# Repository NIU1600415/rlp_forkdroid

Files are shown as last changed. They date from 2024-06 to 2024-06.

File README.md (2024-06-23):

# FORKDROID

Automated forklift with machine vision.

## What is this?

This repository tracks the development of Forkdroid, a machine-vision powered robot which automates moving materials over short distances.
The Forkdroid prototype is a small-form robot actuated by SG90 servomotors with a Raspberry Pi Zero & Pi Camera.

Forkdroid in action

#### Assembled prototype

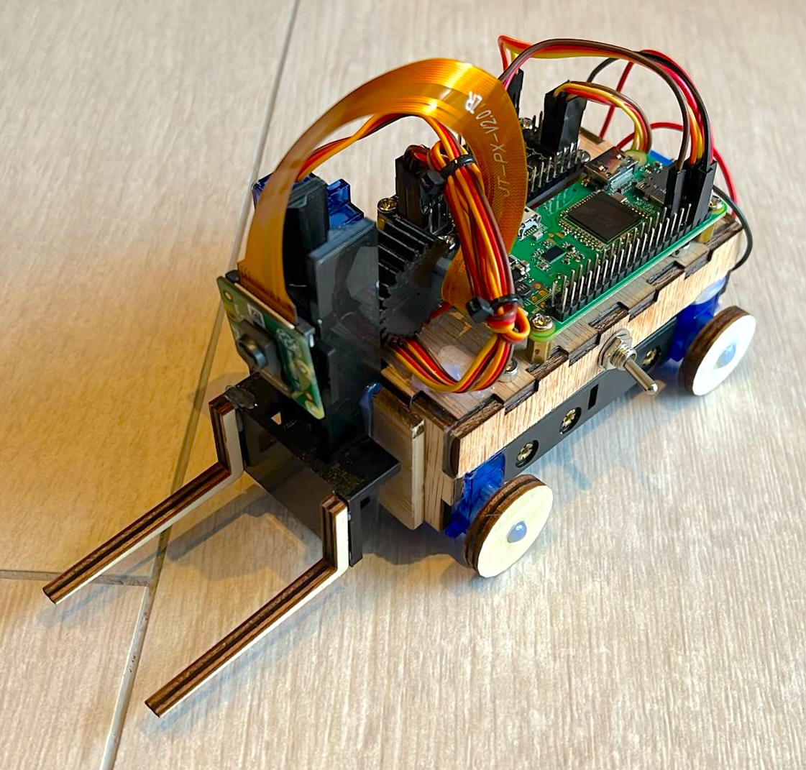
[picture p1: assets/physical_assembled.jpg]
Assembled prototype


#### Vision processing using OpenCV

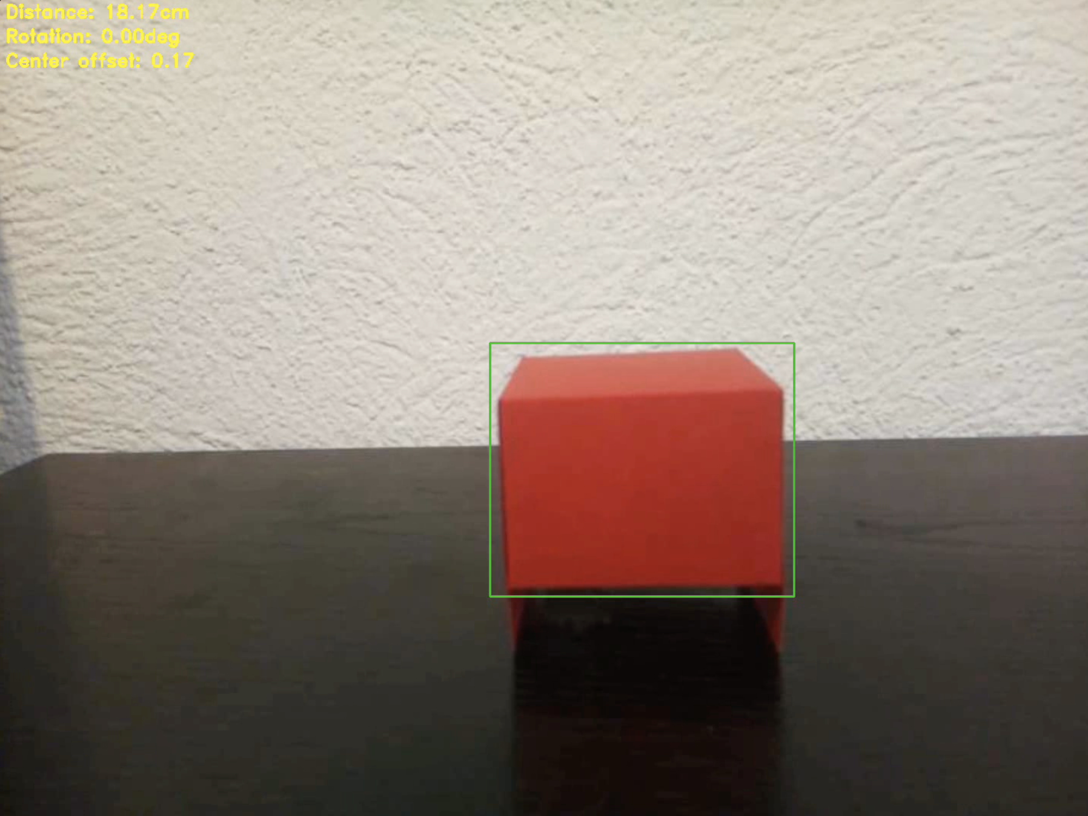
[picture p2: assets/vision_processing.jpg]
Forkdroid vision processing


## Repository structure

### Hardware

Fritzing files

See `schematics/`

### 3D Models

STL files

See `models/`

### Software

See `src/`

### Other files

Simulation scenes, diagrams

See `etc/`

### Todo

[TODO.md](https://github.com/NIU1600415/rlp_forkdroid/blob/main/TODO.md)

## Software

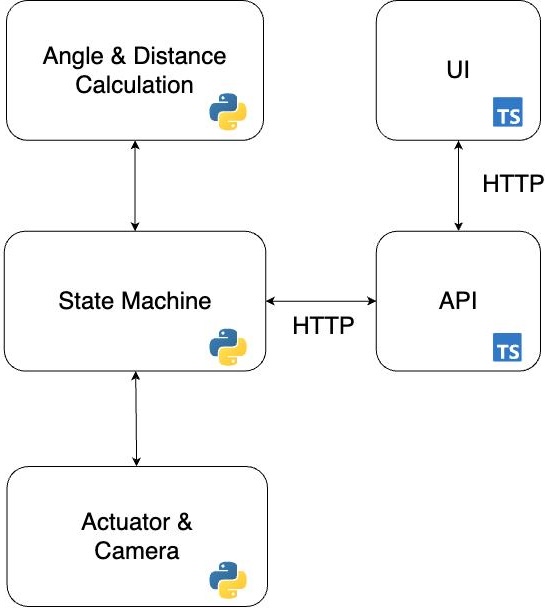
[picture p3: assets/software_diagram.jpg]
Software diagram


### Requirements

- Python 3
- Node >= 14
- Yarn

### Libraries

The minimum required Python libraries are `numpy, opencv & requests`.

For running the simulation, CoppeliaSim is required. See `requirements_sim.txt`.

For running on the Raspberry Pi, `requirements_phys.txt` must be satisfied. It includes Adafruit PCA9685 & picamera2, which should be included with Raspberry Pi OS.

The `server` & `ui` packages have their own npm requirements, and they use `Express` & `Vite`.

### Running

Find how to run either the simulation or the robot package in the [Software README](https://github.com/NIU1600415/rlp_forkdroid/blob/main/src/README.md)

## Hardware

The hardware used on the prototype robot is the following:

- Wifi enabled Raspberry Pi Zero
- Pi Camera rev. 2.1
- Adafruit PCA9685
- SG90 servomotor x5, 4 modified for continuous rotation (wheels)
- x4 2400mAh NiMh batteries, AA form-factor.
- LM2596 DC-DC buck converter (Pi power source)
- Toggle switch

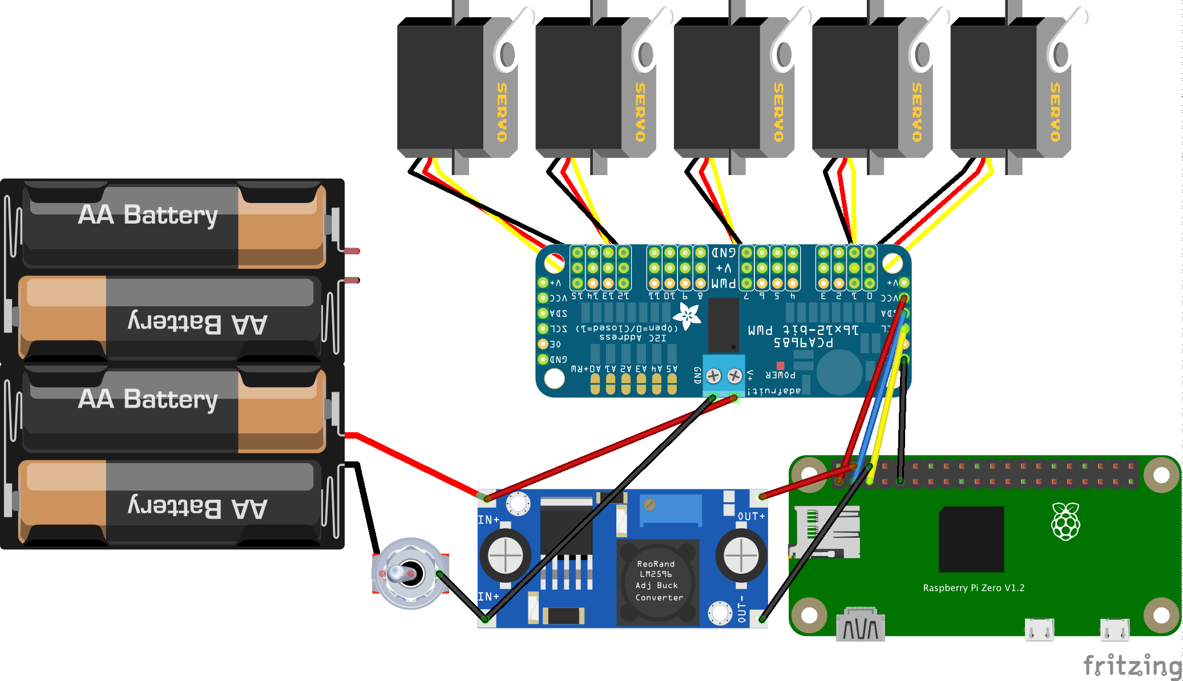
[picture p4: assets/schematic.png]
Hardware schematic


## Modelling

See the [Models README](https://github.com/NIU1600415/rlp_forkdroid/blob/main/models/README.md) for more information.
The prototype modelling was fabricated using a combination of 3D printing and laser cutting.

## LICENSE

MIT

## References

- https://manual.coppeliarobotics.com/en/apiFunctions.htm

- https://datasheets.raspberrypi.com/camera/picamera2-manual.pdf

- https://docs.opencv.org/4.x/d6/d00/tutorial_py_root.html

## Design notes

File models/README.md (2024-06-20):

### 3D Models

- Camera_backboard x1
- Forks_backboard x1
- Inner_rail x1
- Outer_rail x2
- Spur x1

### Laser cutting

- Fork x2
- Inner_body x1
- Outer_body x1
- Wheel x1

### Assembled

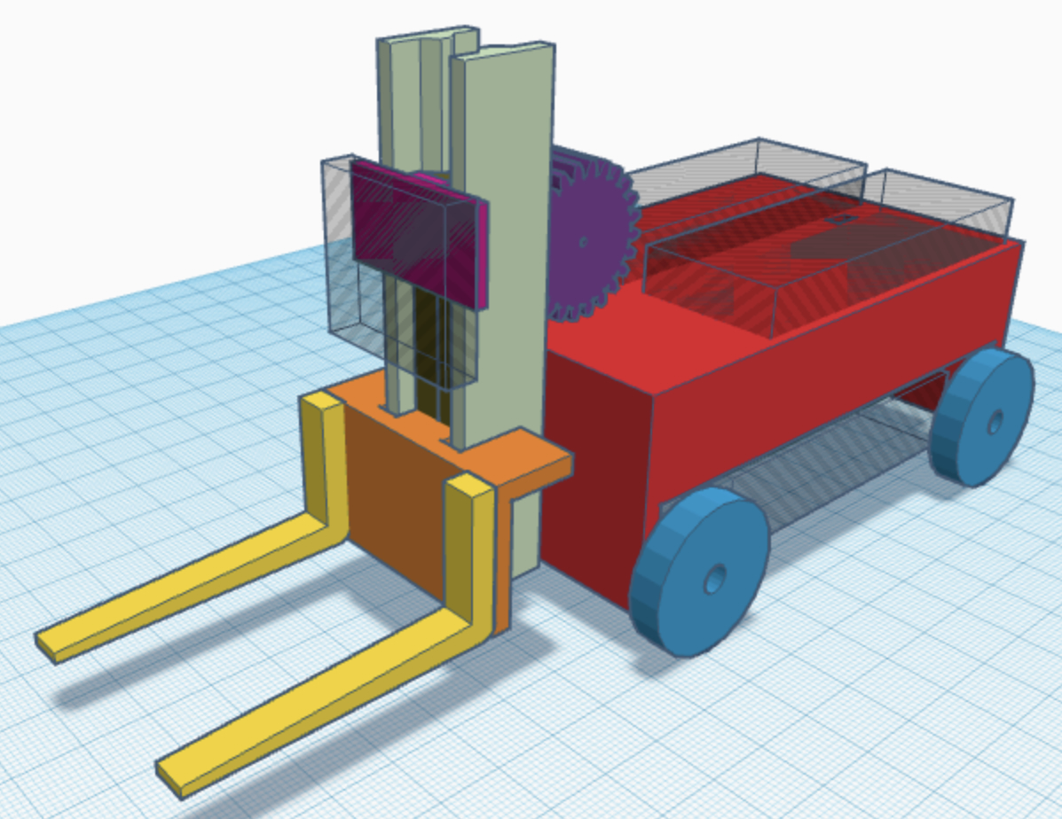
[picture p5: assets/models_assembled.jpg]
Assembled model


Assembled physical

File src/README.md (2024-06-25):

Software diagram

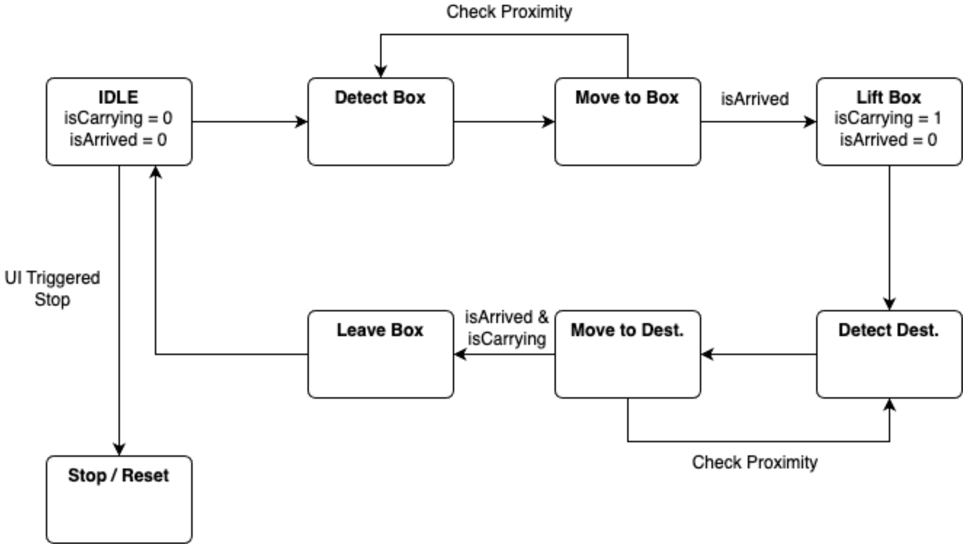
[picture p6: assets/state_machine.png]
State machine


### Before running machine

`$ cd ui && yarn && yarn build && cd ..`

`$ cd server && yarn && yarn start`

### Running sim machine

`$ python run_sim.py`

### Running real machine

`$ python run_phys.py`

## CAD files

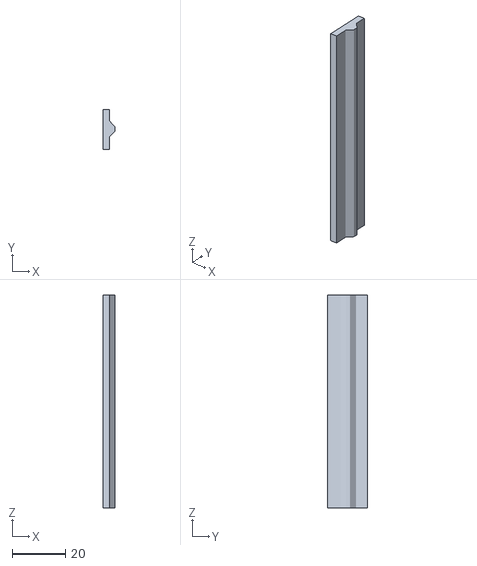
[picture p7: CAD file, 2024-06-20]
models/Outer_rail.stl
4.50 x 15.1 x 80.1

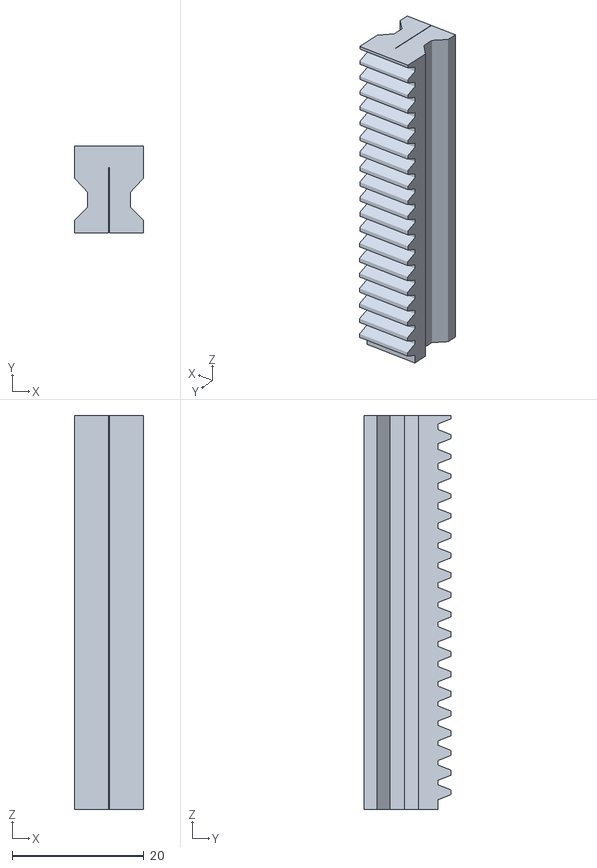
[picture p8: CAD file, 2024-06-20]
models/Inner_rail.stl
10.5 x 13.3 x 59.9

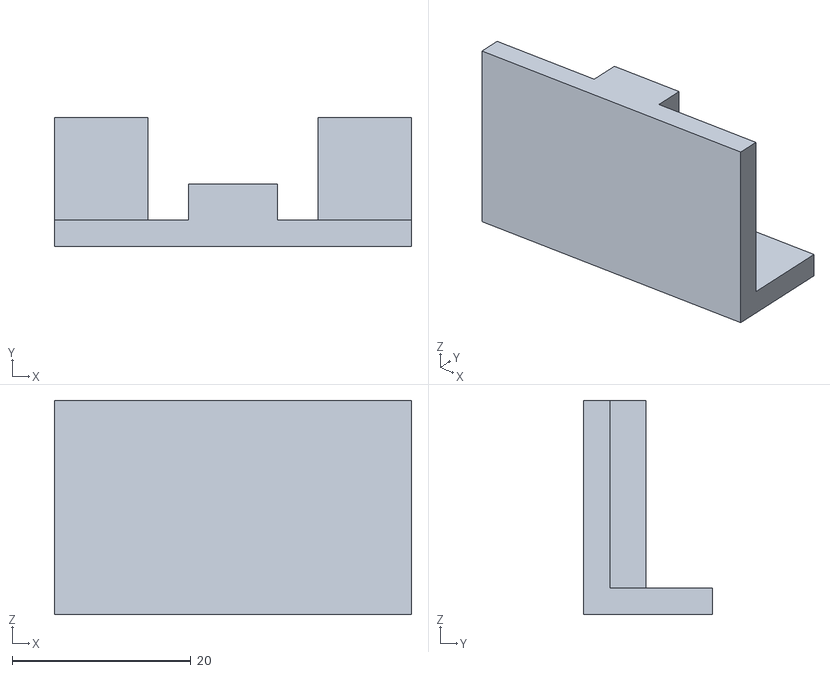
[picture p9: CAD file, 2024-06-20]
models/Forks_backboard.stl
40.0 x 14.5 x 24.0

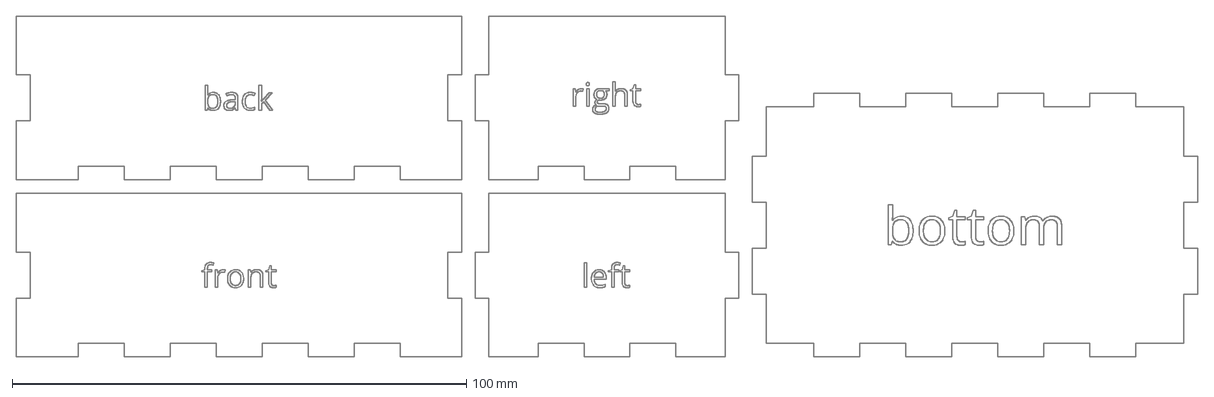
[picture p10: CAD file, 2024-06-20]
models/Outer_body.dxf
260.0 x 75.0 mm

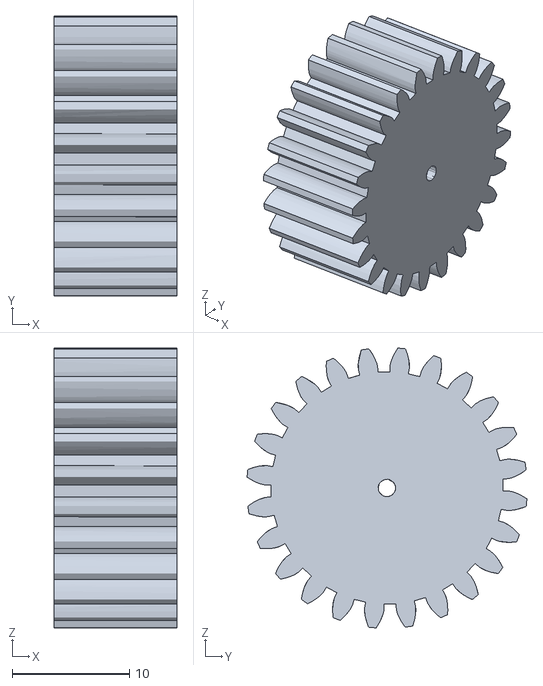
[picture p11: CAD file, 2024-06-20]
models/Spur.stl
10.5 x 23.9 x 23.9

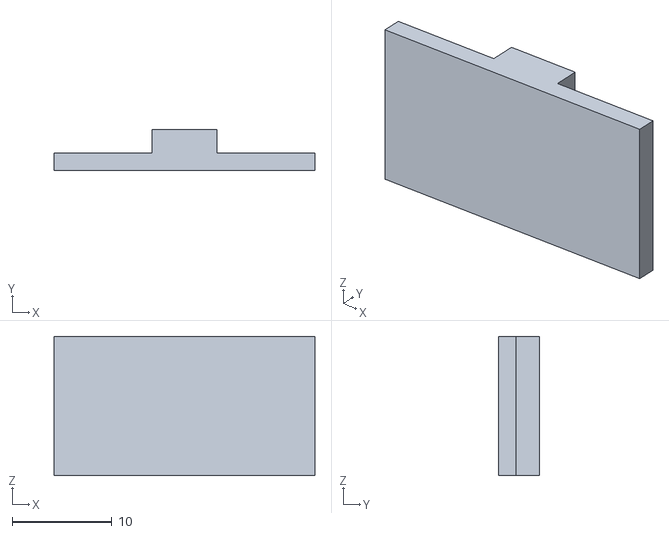
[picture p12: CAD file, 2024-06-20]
models/Camera_backboard.stl
26.2 x 4.08 x 14.0

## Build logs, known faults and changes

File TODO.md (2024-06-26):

### Tasks

- [x] Create repository
- [x] Write basic README
- [x] Add basic code
- [x] Add CoppeliaSim scene
- [x] State machine diagram sketch
- [x] 3D modelling
- [x] Printing & laser cutting model
- [x] Software development
  - [x] HTTP API for UI - machine communication
  - [x] Calibration sequence
  - [x] Vision processing, detecting objects & their properties
  - [x] State machine implementation
  - [x] Web user interface, communication with API
- [x] Robot assembly
- [x] Robot simulation in CoppeliaSim with developed software package
- [x] Demo video
- [x] Update README
- [x] Final report, presentation

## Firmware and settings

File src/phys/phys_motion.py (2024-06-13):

import time
import Adafruit_PCA9685
from lib.motion import Motion

DIRECTIONS = {
    "FR": {
        "STOP": 260,
        "FORWARD": 208,
        "BACKWARD": 322,
    },
    "FL": {
        "STOP": 403,
        "FORWARD": 500,
        "BACKWARD": 300,
    },
    "BL": {
        "STOP": 400,
        "FORWARD": 413,
        "BACKWARD": 390,
    },
    "BR": {
        "STOP": 410,
        "FORWARD": 465,
        "BACKWARD": 350,
    },
}
FORKS_DOWN = 580
FORKS_UP = 150


class PhysMotion(Motion):
    """Motion for the real robot."""

    def __init__(self):
        self.pwm = Adafruit_PCA9685.PCA9685()
        self.pwm.set_pwm_freq(50)
        self.fr_servo_index = 1
        self.fl_servo_index = 2
        self.bl_servo_index = 4
        self.br_servo_index = 5
        self.fork_servo_index = 0

    def _set_fr(self, angle):
        self.pwm.set_pwm(self.fr_servo_index, 0, angle)

    def _set_fl(self, angle):
        self.pwm.set_pwm(self.fl_servo_index, 0, angle)

    def _set_bl(self, angle):
        self.pwm.set_pwm(self.bl_servo_index, 0, angle)

    def _set_br(self, angle):
        self.pwm.set_pwm(self.br_servo_index, 0, angle)

    def _set_forks(self, angle):
        self.pwm.set_pwm(self.fork_servo_index, 0, angle)

    def move_forward(self, duration):
        self._set_fr(DIRECTIONS["FR"]["FORWARD"])
        self._set_fl(DIRECTIONS["FL"]["FORWARD"])
        self._set_bl(DIRECTIONS["BL"]["FORWARD"])
        self._set_br(DIRECTIONS["BR"]["FORWARD"])
        time.sleep(duration)

    def move_backward(self, duration):
        self._set_fr(DIRECTIONS["FR"]["BACKWARD"])
        self._set_fl(DIRECTIONS["FL"]["BACKWARD"])
        self._set_bl(DIRECTIONS["BL"]["BACKWARD"])
        self._set_br(DIRECTIONS["BR"]["BACKWARD"])
        time.sleep(duration)

    def turn_left(self, duration):
        self._set_fr(DIRECTIONS["FR"]["FORWARD"])
        self._set_fl(DIRECTIONS["FL"]["BACKWARD"])
        self._set_bl(DIRECTIONS["BL"]["BACKWARD"])
        self._set_br(DIRECTIONS["BR"]["FORWARD"])
        time.sleep(duration)

    def turn_right(self, duration):
        self._set_fr(DIRECTIONS["FR"]["BACKWARD"])
        self._set_fl(DIRECTIONS["FL"]["FORWARD"])
        self._set_bl(DIRECTIONS["BL"]["FORWARD"])
        self._set_br(DIRECTIONS["BR"]["BACKWARD"])
        time.sleep(duration)

    def stop(self):
        self._set_fr(DIRECTIONS["FR"]["STOP"])
        self._set_fl(DIRECTIONS["FL"]["STOP"])
        self._set_bl(DIRECTIONS["BL"]["STOP"])
        self._set_br(DIRECTIONS["BR"]["STOP"])

    def put_forks_down(self):
        self._set_forks(FORKS_DOWN)

    def lift_target(self):
        self._set_forks(FORKS_UP)

    def place_target(self):
        self.put_forks_down()

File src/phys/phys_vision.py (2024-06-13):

from picamera2 import Picamera2
from lib.vision import Vision
from vision_processing.vision_processing import (
    analyze_frame_for_target_object,
    analyze_frame_for_destination,
)
from vision_processing.vision_processing import (
    TargetAnalysisResult,
    DestinationAnalysisResult,
)


class PhysVision(Vision):
    """Vision for the real robot (Pi camera)"""

    def __init__(self):
        self.picam2 = Picamera2()
        self.picam2.configure(self.picam2.create_still_configuration())
        self.picam2.start()

    def get_frame(self):
        return self.picam2.capture_array()

    def detect_target(self) -> TargetAnalysisResult:
        frame = self.get_frame()
        analysis_result = analyze_frame_for_target_object(frame, debug=True)
        return analysis_result

    def detect_dest(self) -> DestinationAnalysisResult:
        frame = self.get_frame()
        analysis_result = analyze_frame_for_destination(frame, debug=True)
        return analysis_result

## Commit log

2024-06-03 Add function for analyzing frames for destination
2024-06-03 Allow storing intermediate debug frames in vision processing
2024-06-04 Fix exception when no target found in video processing frame analysis
2024-06-10 Stop/start robot from web UI (#13)
    * Start / Stop button added
    * Formatting
    ---------
2024-06-17 Add Fritzing schematic
    [forkdroid.fzz]
2024-06-20 Add 3D models, assembly images & associated README
    [Camera_backboard.stl, Forks_backboard.stl, Inner_rail.stl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]
2024-06-21 Update schematic to add toggle switch
    [forkdroid.fzz]
